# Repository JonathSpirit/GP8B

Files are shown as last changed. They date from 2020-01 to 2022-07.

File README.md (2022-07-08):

# GP8B - GProcessor8Bits

Copyright (C) 2022 Guillaume Guillet\
Licensed under CERN-OHL-W v2 or later

<table border="0px">
<tr>
<td>
This source describes Open Hardware and is licensed under the CERN-OHL-W v2 or later.
</td>
</tr>
<tr>
<td>
You may redistribute and modify this documentation and make products
using it under the terms of the CERN-OHL-W v2 (https:/cern.ch/cern-ohl).
This documentation is distributed WITHOUT ANY EXPRESS OR IMPLIED
WARRANTY, INCLUDING OF MERCHANTABILITY, SATISFACTORY QUALITY
AND FITNESS FOR A PARTICULAR PURPOSE. Please see the CERN-OHL-W v2
for applicable conditions.
</td>
</tr>
</table>

Made with [Kicad](https://kicad.org/)

## Description
G_Processor8Bits is a homemade, without any microcontroller, 8bits processor.

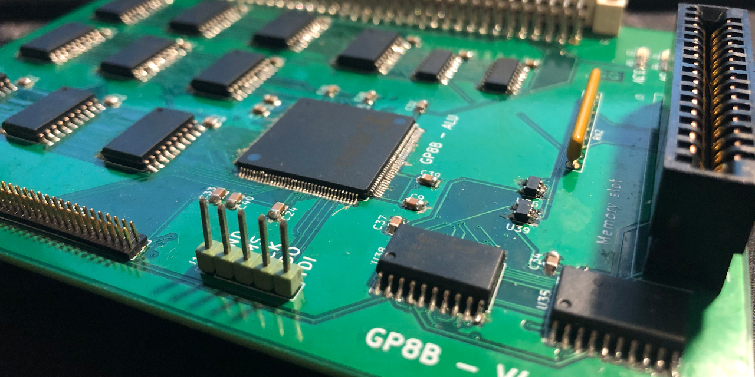
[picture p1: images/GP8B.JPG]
GP8B_image
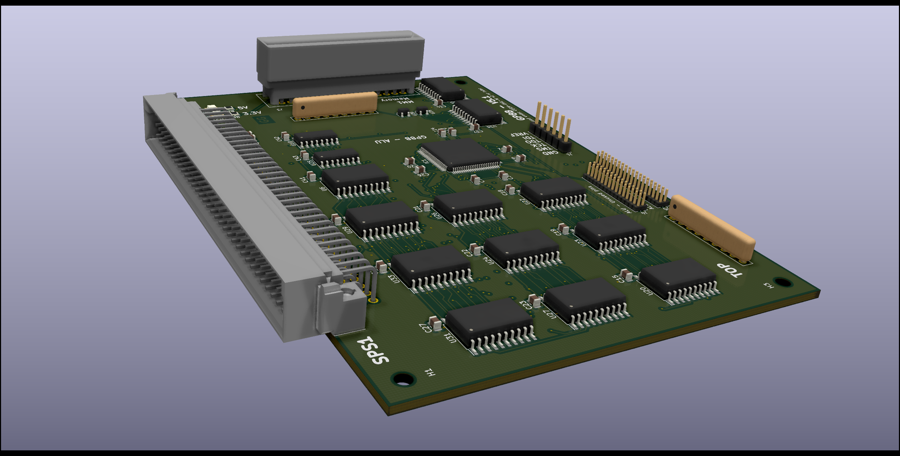
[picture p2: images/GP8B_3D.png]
GP8B_3D_image
 
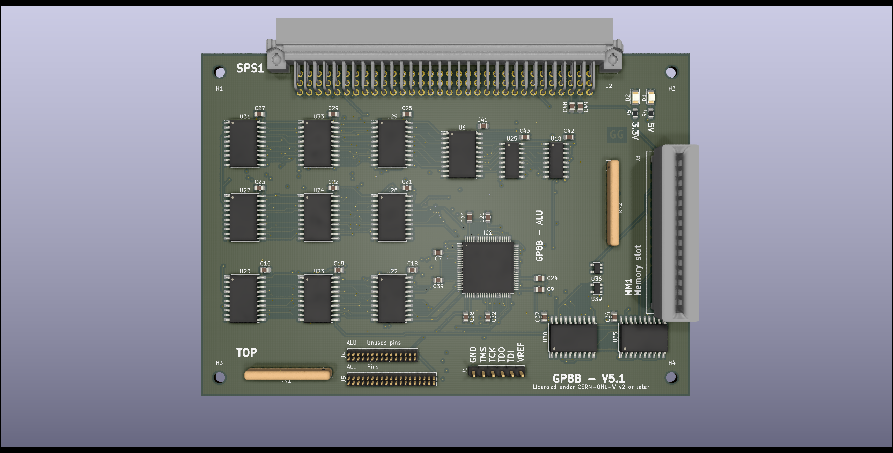
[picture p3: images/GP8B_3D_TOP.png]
GP8B_3D_TOP_image
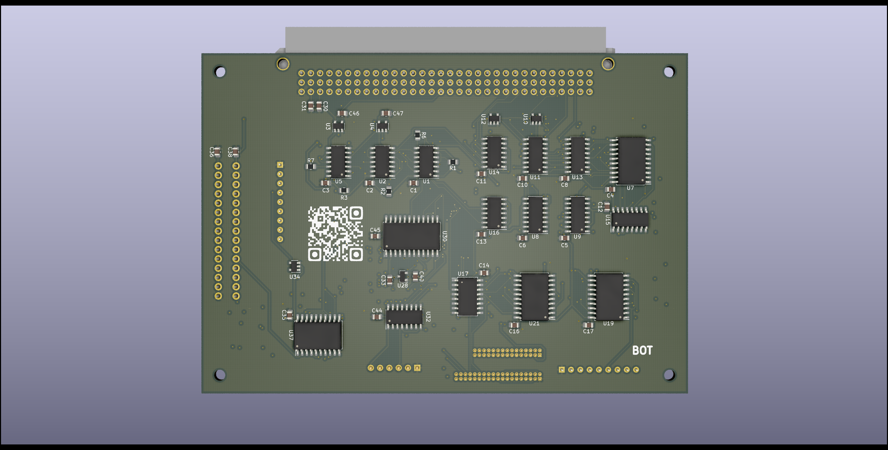
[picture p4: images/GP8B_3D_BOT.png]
GP8B_3D_BOT_image
 

## Stats





\
\
\


## Block diagram

[Block diagram (.pdf)](documents/blockDiagram/GP8B_blockDiagram.pdf)

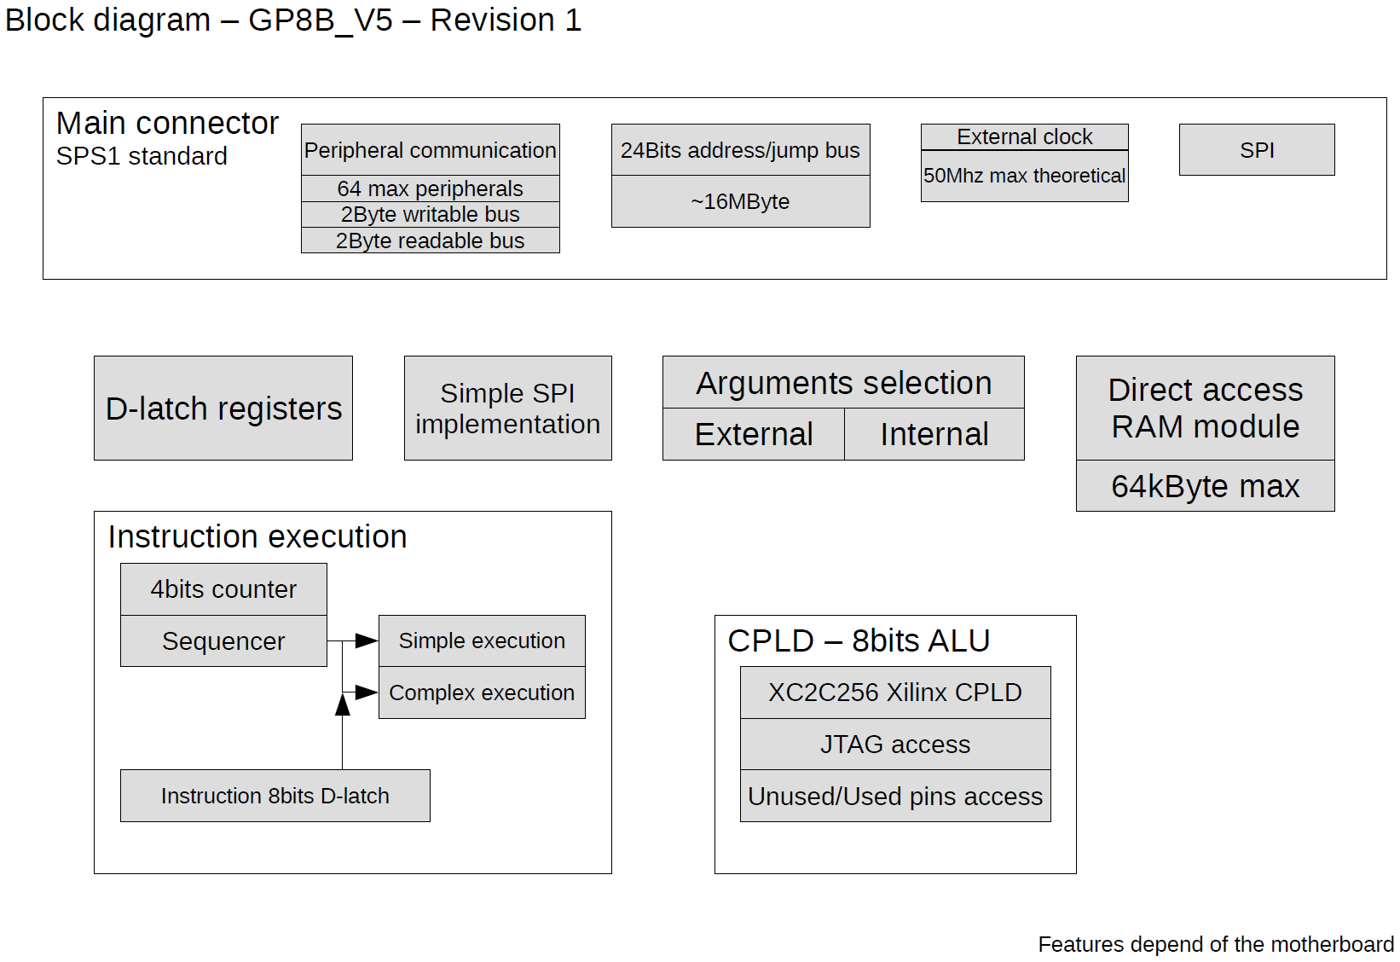
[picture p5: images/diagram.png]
Image of diagram


## Instruction sets
GP8B follow [CodeG_binary (revision 1)](https://github.com/JonathSpirit/GComputer_standard)

8bits instuction is separated in 2 category :
```
-------------- Argument selection
|||  
||| ---------- Opcode
||| |||||
000 00000
```
**5bits for opcode :**
```
OPCODE      HEX     NAME            DESCRIPTION
xxx0’0000   0x00    BWRITE1_CLK     Apply value to bus “write 1”.
xxx0’0001   0x01    BWRITE2_CLK     Apply value to bus “write 2”.
xxx0’0010   0x02    BPCS_CLK        Apply value to bus “peripheral CS”.
xxx0’0011   0x03    OPLEFT_CLK      Apply value to the left operation.
xxx0’0100   0x04    OPRIGHT_CLK     Apply value to the right operation.
xxx0’0101   0x05    OPCHOOSE_CLK    Apply value for choosing the operation.
xxx0’0110   0x06    PERIPHERAL_CLK  Send a clock pulse to the peripheral.
xxx0’0111   0x07    BJMPSRC1_CLK    Apply value to bus “jump source 1”.
xxx0’1000   0x08    BJMPSRC2_CLK    Apply value to bus “jump source 2”.
xxx0’1001   0x09    BJMPSRC3_CLK    Apply value to bus “jump source 3”.
xxx0’1010   0x0A    JMPSRC_CLK      Jump to the address of “jump source”.
xxx0’1011   0x0B    BRAMADD1_CLK    Apply value to bus “RAM address 1”.
xxx0’1100   0x0C    BRAMADD2_CLK    Apply value to bus “RAM address 2”.
xxx0’1101   0x0D    SPI_CLK         Send a clock pulse for the SPI.
xxx0’1110   0x0E    BCFG_SPI_CLK    Apply value to the config bus SPI.
xxx0’1111   0x0F    STICK           Simple tick, do nothing (delay).
xxx1’0000   0x10    IF              Conditional instruction.
xxx1’0001   0x11    IFNOT           Conditional instruction inverted.
xxx1’0010   0x12    RAMW            Write value to the actual address of the memory.
xxx1’0011   0x13    UOP             Undefined operation.
xxx1’0100   0x14    UOP             Undefined operation.
xxx1’0101   0x15    UOP             Undefined operation.
xxx1’0110   0x16    UOP             Undefined operation.
xxx1’0111   0x17    LTICK           Long tick, do nothing (delay).
```
**3bits for argument selection :**
```
OPCODE      HEX     NAME            DESCRIPTION
000x’xxxx   0x00    SRCVALUE        The value stored to the source.
001x’xxxx   0x20    BREAD1          The value of the read bus 1.
010x’xxxx   0x40    BREAD2          The value of the read bus 2.
011x’xxxx   0x60    OPRESULT        The value of the operation result (ALU).
100x’xxxx   0x80    RAMVALUE        The value of the processor memory.
101x’xxxx   0xA0    SPI             The value of the SPI.
110x’xxxx   0xC0    EXT_1           External value 1.
111x’xxxx   0xE0    EXT_2           External value 2.
```

## Processor standard
This processor, follow the [SPS1](https://github.com/JonathSpirit/GComputer_standard) standard

## Compatibility
Compatible with all motherboard following the [MOM1_SPS1](https://github.com/JonathSpirit/GComputer_standard) standard

## Documents
[Block diagram (.pdf)](documents/blockDiagram/GP8B_blockDiagram.pdf)

[Schematics (.pdf)](documents/GP8B_schematics.pdf)

[Materials (.pdf)](documents/GP8B_materials.pdf)

[Datasheet (.pdf)](documents/GP8B_datasheet.pdf)

## Contributing / Questions
Please see [Contributing file](CONTRIBUTING.md)

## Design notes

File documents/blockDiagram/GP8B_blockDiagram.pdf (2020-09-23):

## Main connector

SPS1 standard

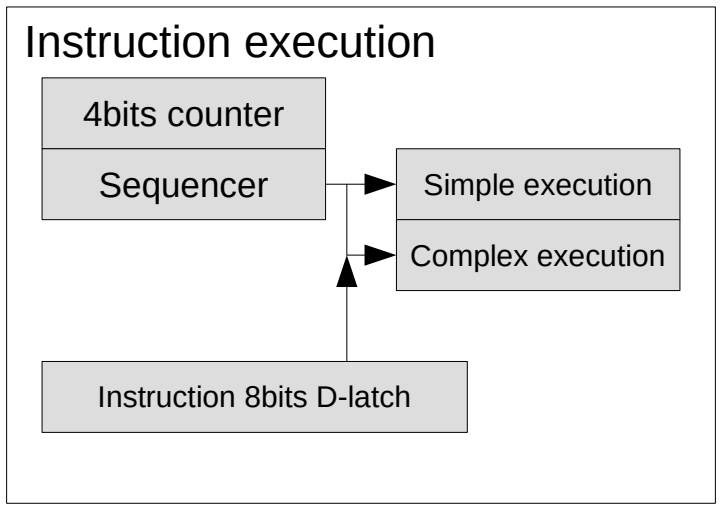
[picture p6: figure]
Instruction execution; 4bits counter; Sequencer; Instruction 8bits D-latch; Simple execution; Complex execution

## CPLD – 8bits ALU

## D-latch registers

Arguments selection | Direct access RAM module

### Simple SPI implementation

## External Internal 64kByte max

External clock

50Mhz max theoretical

Peripheral communication 24Bits address/jump bus 64 max peripherals

XC2C256 Xilinx CPLD

JTAG access

Unused/Used pins access

## Block diagram – GP8B_V5 – Revision 1

2Byte readable bus

2Byte writable bus

SPI

~16MByte

Features depend of the motherboard

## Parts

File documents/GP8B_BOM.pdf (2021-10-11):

1

GP8B_materials.fods

| GP8B | V5.1
Author : Guillaume Guillet | Revision 1 | Licensed under CERN-OHL-W v2 or later
Type | Value | Q | References | Package | Manufacturer | Store | Store ID | Unit price* | Price
C | 10nF | 33 | C1 to C6, C8, C10 to C19, C21 to C23, C25, C27, C29, C34, C35, C37, C41 to C47 | C_0805_2012Metric | Wurth Elektronik | Mouser | 710-885012207066 | 0.033 | 1.089
| 100nF | 12 | C7, C9, C20, C24, C26, C28, C30 to C32, C36, C38, C39 | C_0805_2012Metric | Wurth Elektronik | Mouser | 710-885012207072 | 0.072 | 0.864
| 1uF | 4 | C33, C40, C48, C49 | C_0805_2012Metric | Wurth Elektronik | Mouser | 710-885012207078 | 0.094 | 0.376
U | 74AHC08 | 2 | U16,U14 | SOIC-14_3.9x8.7mm_P1.27mm | Texas Instruments | Mouser | 595-SN74AHC08QDRQ1 | 0.459 | 0.918
| 74AHC273 | 9 | U6, U24, U26, U27, U29, U31, U33, U35, U37 | SOIC-20W_7.5x12.8mm_Pitch1.27mm | Texas Instruments | Mouser | 595-SN74AHC273DWR | 0.431 | 3.879
| 74AHCT273 | 1 | U7 | SOIC-20W_7.5x12.8mm_Pitch1.27mm | Texas Instruments | Mouser | 595-SN74AHCT273DWR | 0.524 | 0.524
| 74HC163 | 1 | U8 | SOIC-16_3.9x9.9mm_P1.27mm | Texas Instruments | Mouser | 595-SN74HC163D | 0.421 | 0.421
| CD74AC238 | 4 | U9, U11, U13, U15 | SOIC-16_3.9x9.9mm_P1.27mm | Texas Instruments | Mouser | 595-CD74AC238M96 | 0.591 | 2.364
| 74AHCT244 | 5 | U19 à U23 | SOIC-20W_7.5x12.8mm_Pitch1.27mm | Texas Instruments | Mouser | 595-SN74AHCT244DWR | 0.478 | 2.39
| 74AHC138 | 1 | U17 | SOIC-16W_5.3x10.2mm_P1.27mm | Texas Instruments | Mouser | 595-SN74AHC138NSR | 0.394 | 0.394
| 74HC166 | 1 | U18 | SOIC-16_3.9x9.9mm_P1.27mm | Texas Instruments | Mouser | 595-SN74HC166DRE4 | 0.45 | 0.45
| 74LVC1G34 | 1 | U34 | SOT-23-5 | Texas Instruments | Mouser | 595-SN74LVC1G34DBVR | 0.3 | 0.3
| 74AHCT595 | 1 | U25 | SOIC-16_3.9x9.9mm_P1.27mm | Texas Instruments | Mouser | 595-SN74AHCT595DR | 0.431 | 0.431
| 74AHC05 | 3 | U1, U2, U5 | SOIC-14_3.9x8.7mm_P1.27mm | Texas Instruments | Mouser | 595-SN74AHC05D | 0.431 | 1.293
| 74AHC374 | 1 | U38 | SOIC-20W_7.5x12.8mm_Pitch1.27mm | Texas Instruments | Mouser | 595-SN74AHC374DWR | 0.524 | 0.524
| 74AHC1G04 | 4 | U10, U12, U36, U39 | SOT-23-5 | Texas Instruments | Mouser | 595-SN74AHC1G04DBVR | 0.3 | 1.2
| 74AHC1G02 | 1 | U3 | SOT-23-5 | Texas Instruments | Mouser | 595-SN74AHC1G02DBE4 | 0.45 | 0.45
| 74AHC1G08 | 1 | U4 | SOT-23-5 | Texas Instruments | Mouser | 595-SN74AHC1G08DBV3 | 0.421 | 0.421
| TPS7A0518PDBZR | 1 | U28 | SOT-23-3 | Texas Instruments | Mouser | 595-TPS7A0518PDBZR | 0.591 | 0.591
| SN74LVC8T245DW | 1 | U30 | SOIC-24W_7.5x15.4mm_P1.27mm | Texas Instruments | Mouser | 595-SN74LVC8T245DWR | 1.01 | 1.01
| SN74LVC4T245D | 1 | U32 | SOIC-16_3.9x9.9mm_P1.27mm | Texas Instruments | Mouser | 595-SN74AVC4T245D | 1.04 | 1.04
| XC2C256-VQ100 | 1 | IC1 | VQFP-100_14x14mm_P0.5mm | Xilinx Inc, | Mouser | 217-XC2C256-7VQG100C | 18.08 | 18.08
R | 470E | 1 | R5 | R_0805_2012Metric | Bourns | Mouser | 652-CR0805FX-4700ELF | 0.094 | 0.094

# Project :

2

GP8B_materials.fods

| 1k5 | 1 | R4 | R_0805_2012Metric | Bourns | Mouser | 652-CR0805FX-1501ELF | 0.094 | 0.094
| 10k | 5 | R1, R2, R3, R6, R7 | R_0805_2012Metric | Bourns | Mouser | 652-CR0805-JW-103ELF | 0.094 | 0.47
RN | 8x10k | 2 | RN1, RN2 | R_Array_SIP9 | Bourns | Mouser | 652-4609H-1LF-10K | 0.562 | 1.124
D | GREEN_2.65V_2mA | 2 | D1, D2 | LED_1206_3216Metric | Kingbright | Mouser | 604-APT3216LZGCK | 0.414 | 0.828
J | TE_Eurocard_96pole | 1 | J2 | Eurocard_5650473-5 | TE connectivity | Mouser | 571-5650473-5 | 4.83 | 4.83
| 5530843-2 | 1 | J3 | TE_5530843-2 | TE connectivity | Mouser | 571-5530843-2 | 2.44 | 2.44
| Conn_01x06_Male | 1 | J1 | PinHeader_1x06_P2.54mm_Vertical | TE connectivity | Mouser | 571-826936-6 | 0.487 | 0.487
| Conn_02x15_Male | 1 | J4 | PinHeader_2x15_P1.27mm_Vertical | Samtec | Mouser | 200-TMS11501GD | 5.01 | 5.01
| Conn_02x19_Male | 1 | J5 | PinHeader_2x19_P1.27mm_Vertical | Samtec | Mouser | 200-TMS12001GD | 6.43 | 6.43
- | PCB_GP8B_V5.1 | 1 | - | - | G.Guillet | - | | | 0
Total price : | 60.816
*Depend of the quantity | Price is in CHF

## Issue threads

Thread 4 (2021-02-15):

Fix the SPI 4bits only issue

JonathSpirit, 2021-02-15:
by putting 74HC166 instead of 74HC165, it is possible to load directly 8bits into the serial shifter and do a much better SPI implementation

JonathSpirit, 2021-03-04:
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

Closed 2021-10-11.

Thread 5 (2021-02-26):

Replace symbol for IC1

JonathSpirit, 2021-02-26:
There is a new symbol in kicad for the XC2C256

Closed 2021-10-11.

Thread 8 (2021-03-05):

Don't go to the next address if the argument isn't SRCVALUE

JonathSpirit, 2021-03-05:
Currently when you are selecting an argument like th operation result (OPRESULT), you have to provide an dummy argument after the instruction in the code :

0x60 (BWRITE1_CLK instruction with an OPRESULT argument)
0x00 (dummy value)
0x61 (BWRITE2_CLK instruction with an OPRESULT argument)
0x00 (dummy value)
0xB2 (RAMW instruction with an SPI argument)
0x00 (dummy value)

The goal is to remove this dummy value when the user select another argument that SRCVALUE.
It will significantly decrease code size.

It will become like this :

0x60 (BWRITE1_CLK instruction with an OPRESULT argument)
0x61 (BWRITE2_CLK instruction with an OPRESULT argument)
0xB2 (RAMW instruction with an SPI argument)

JonathSpirit, 2021-03-05:
fed9e0c65bced2c1cab43c469c3624e4797e8039

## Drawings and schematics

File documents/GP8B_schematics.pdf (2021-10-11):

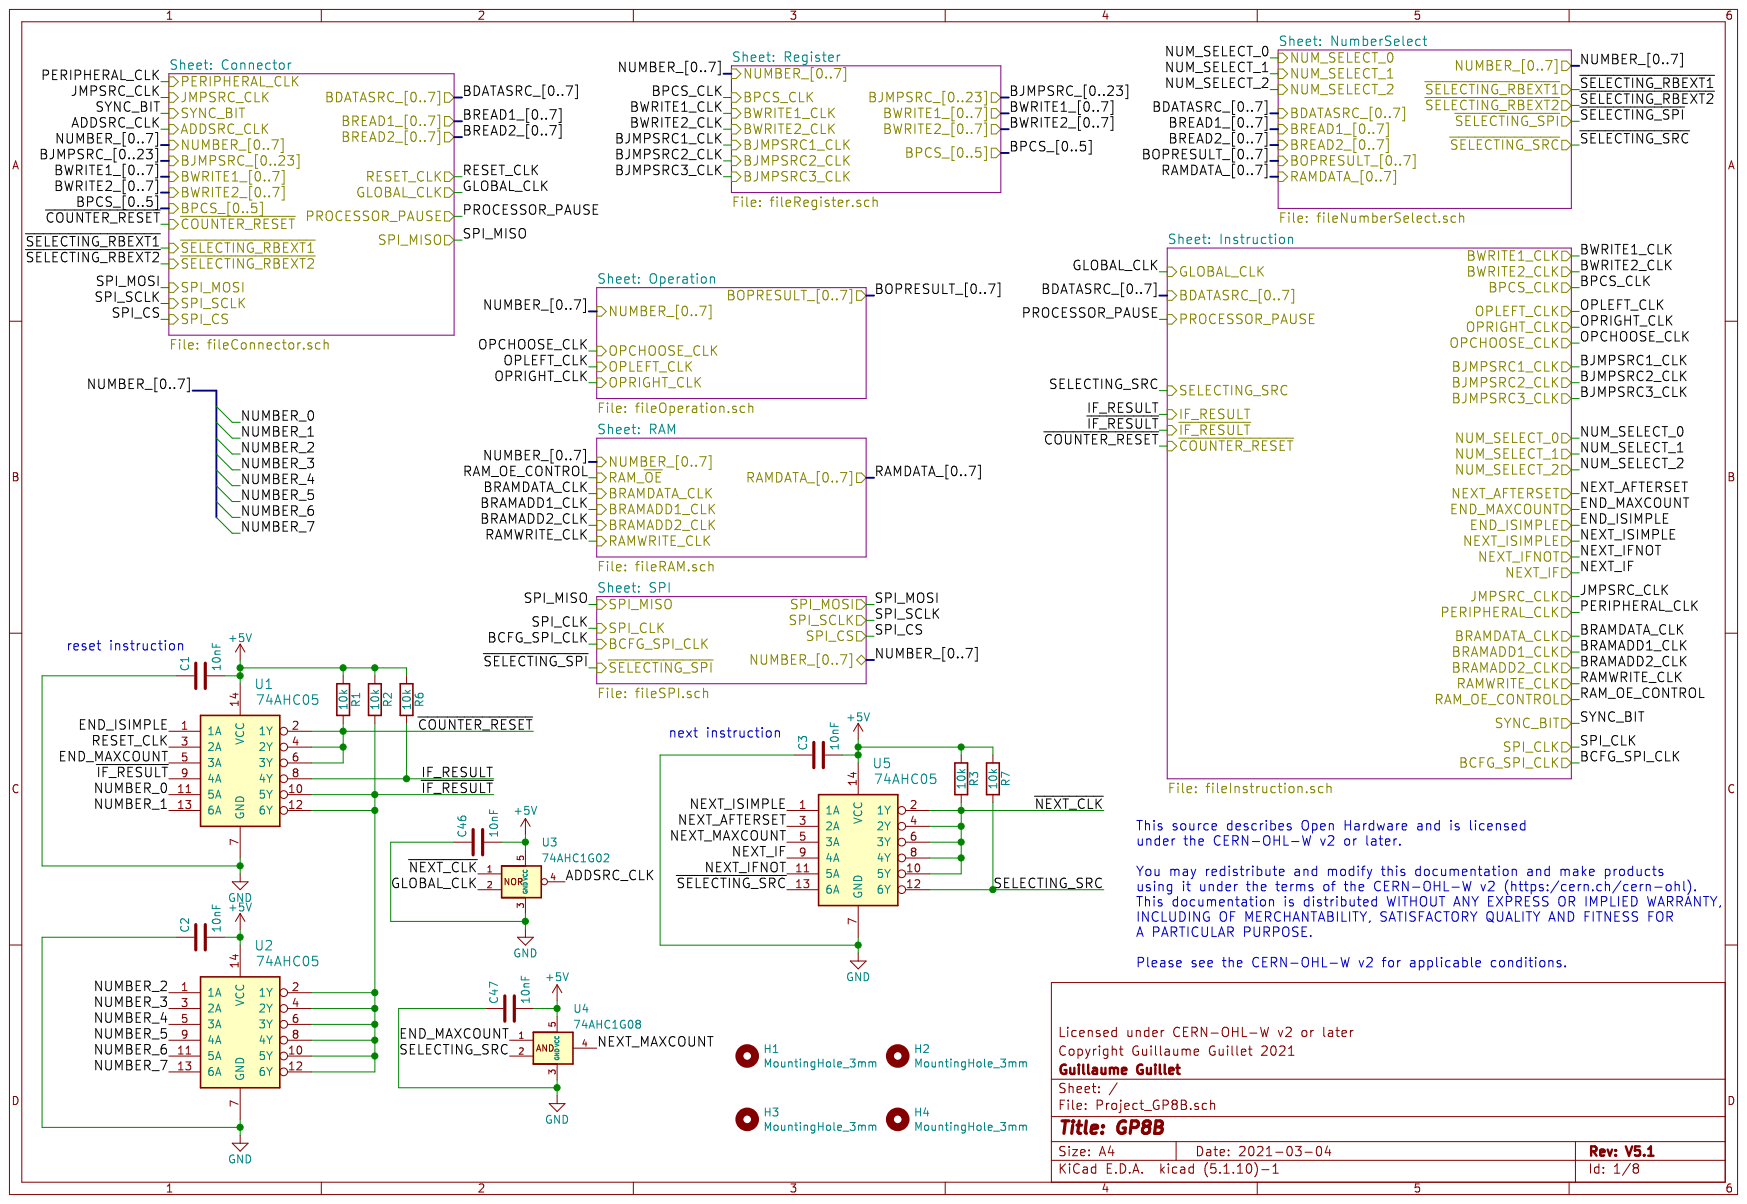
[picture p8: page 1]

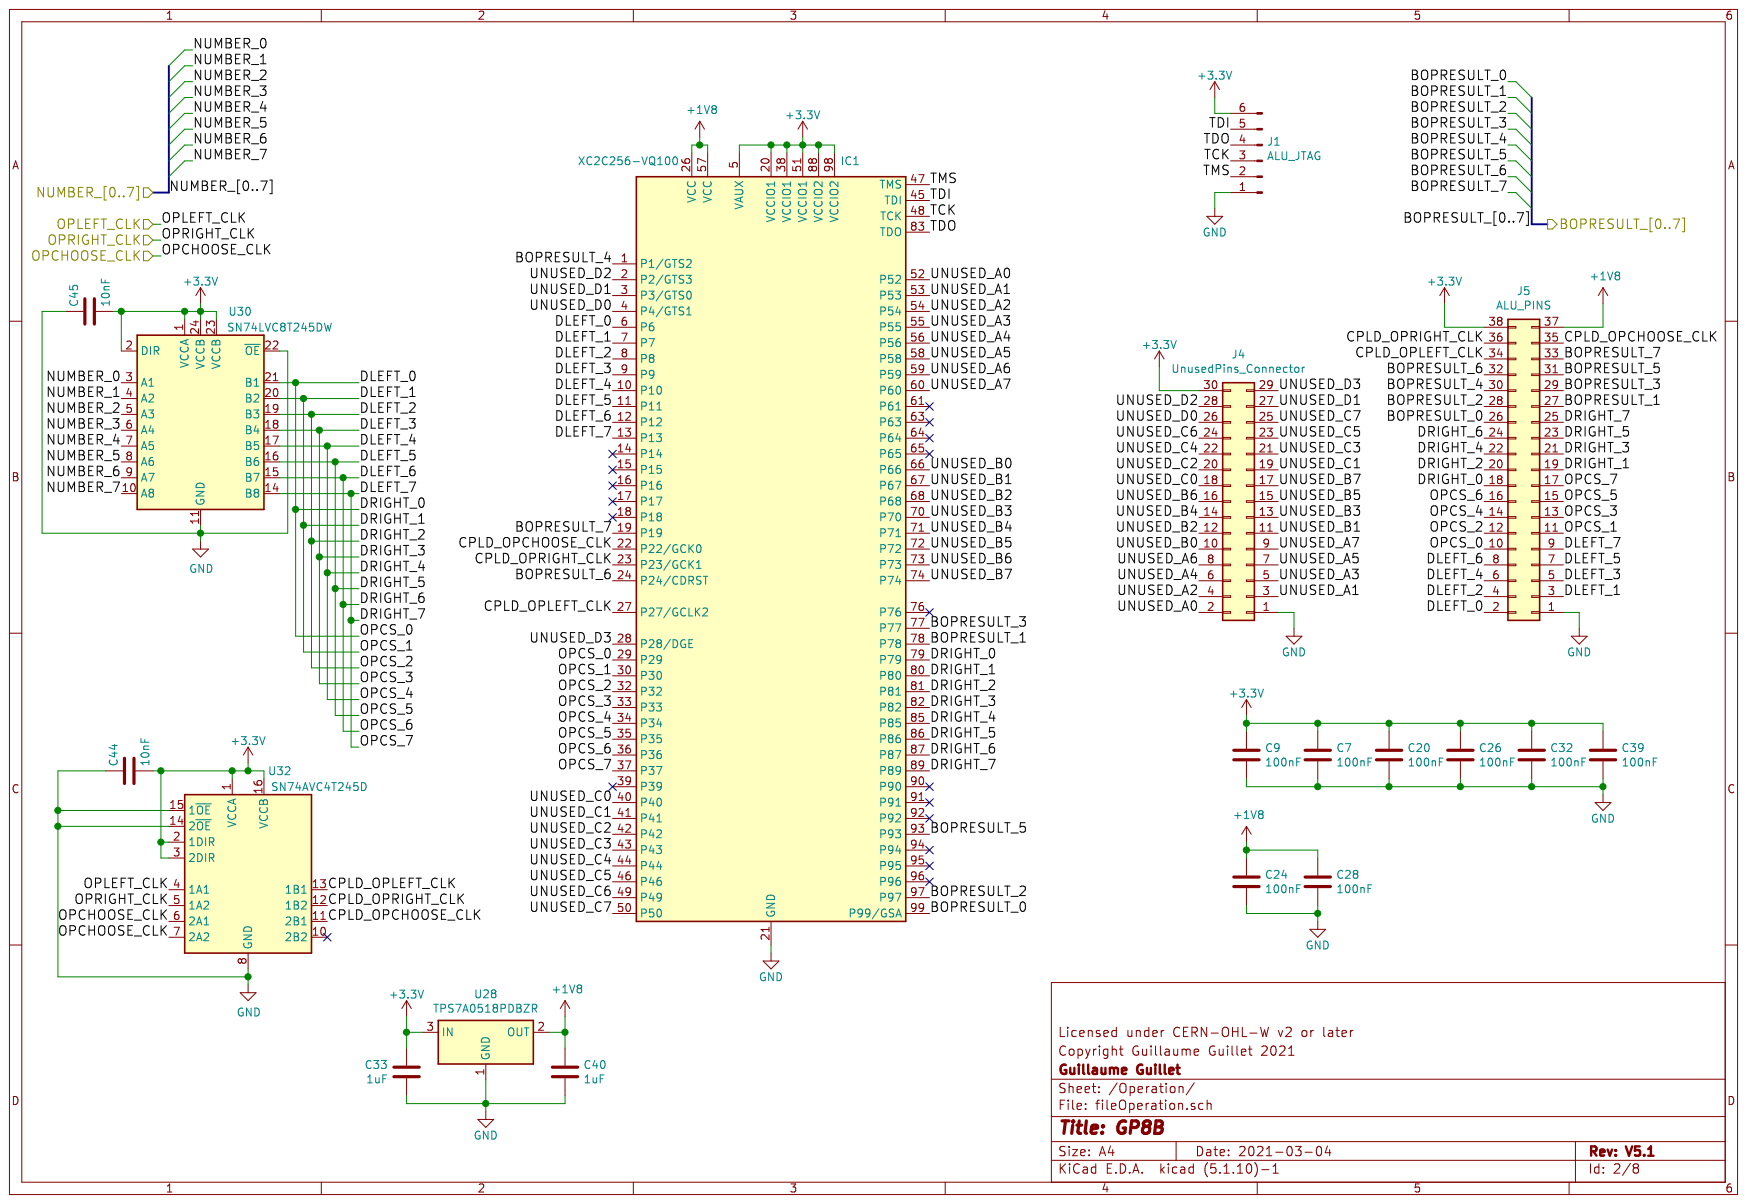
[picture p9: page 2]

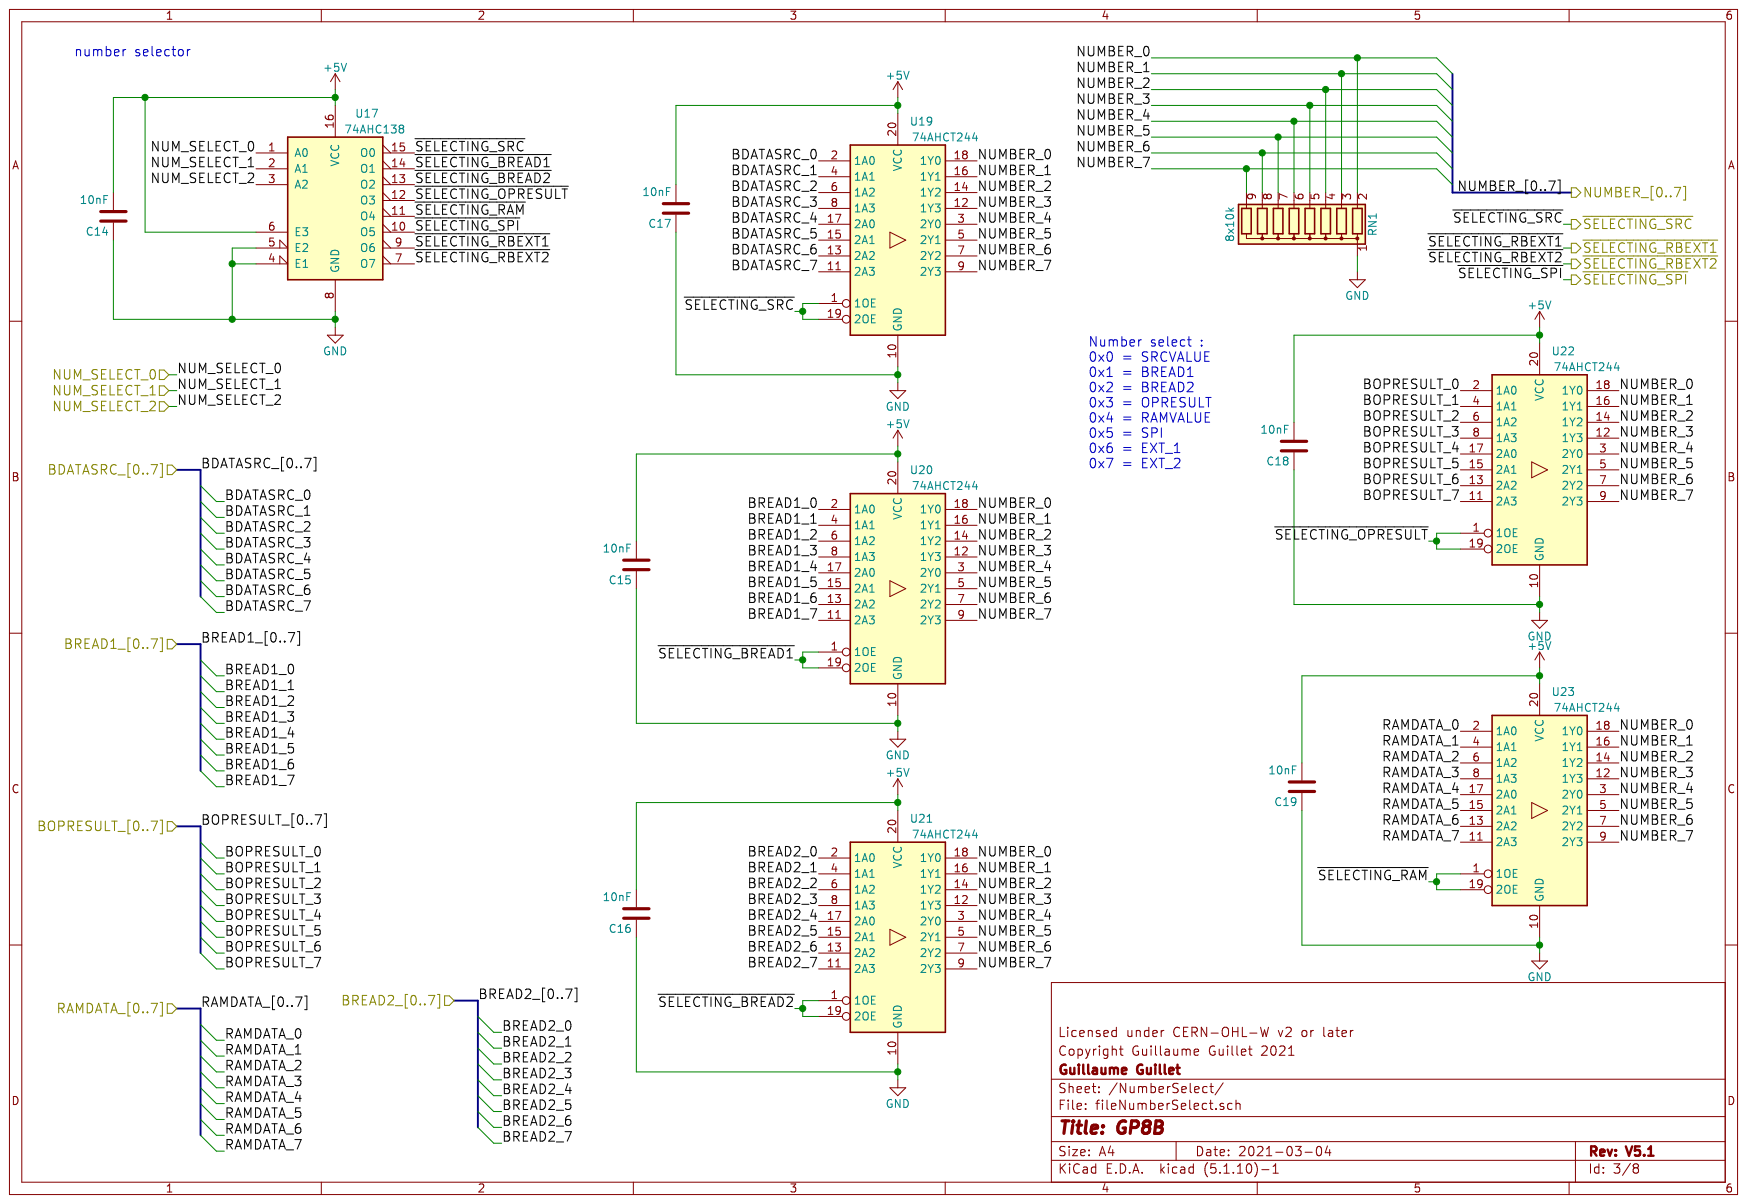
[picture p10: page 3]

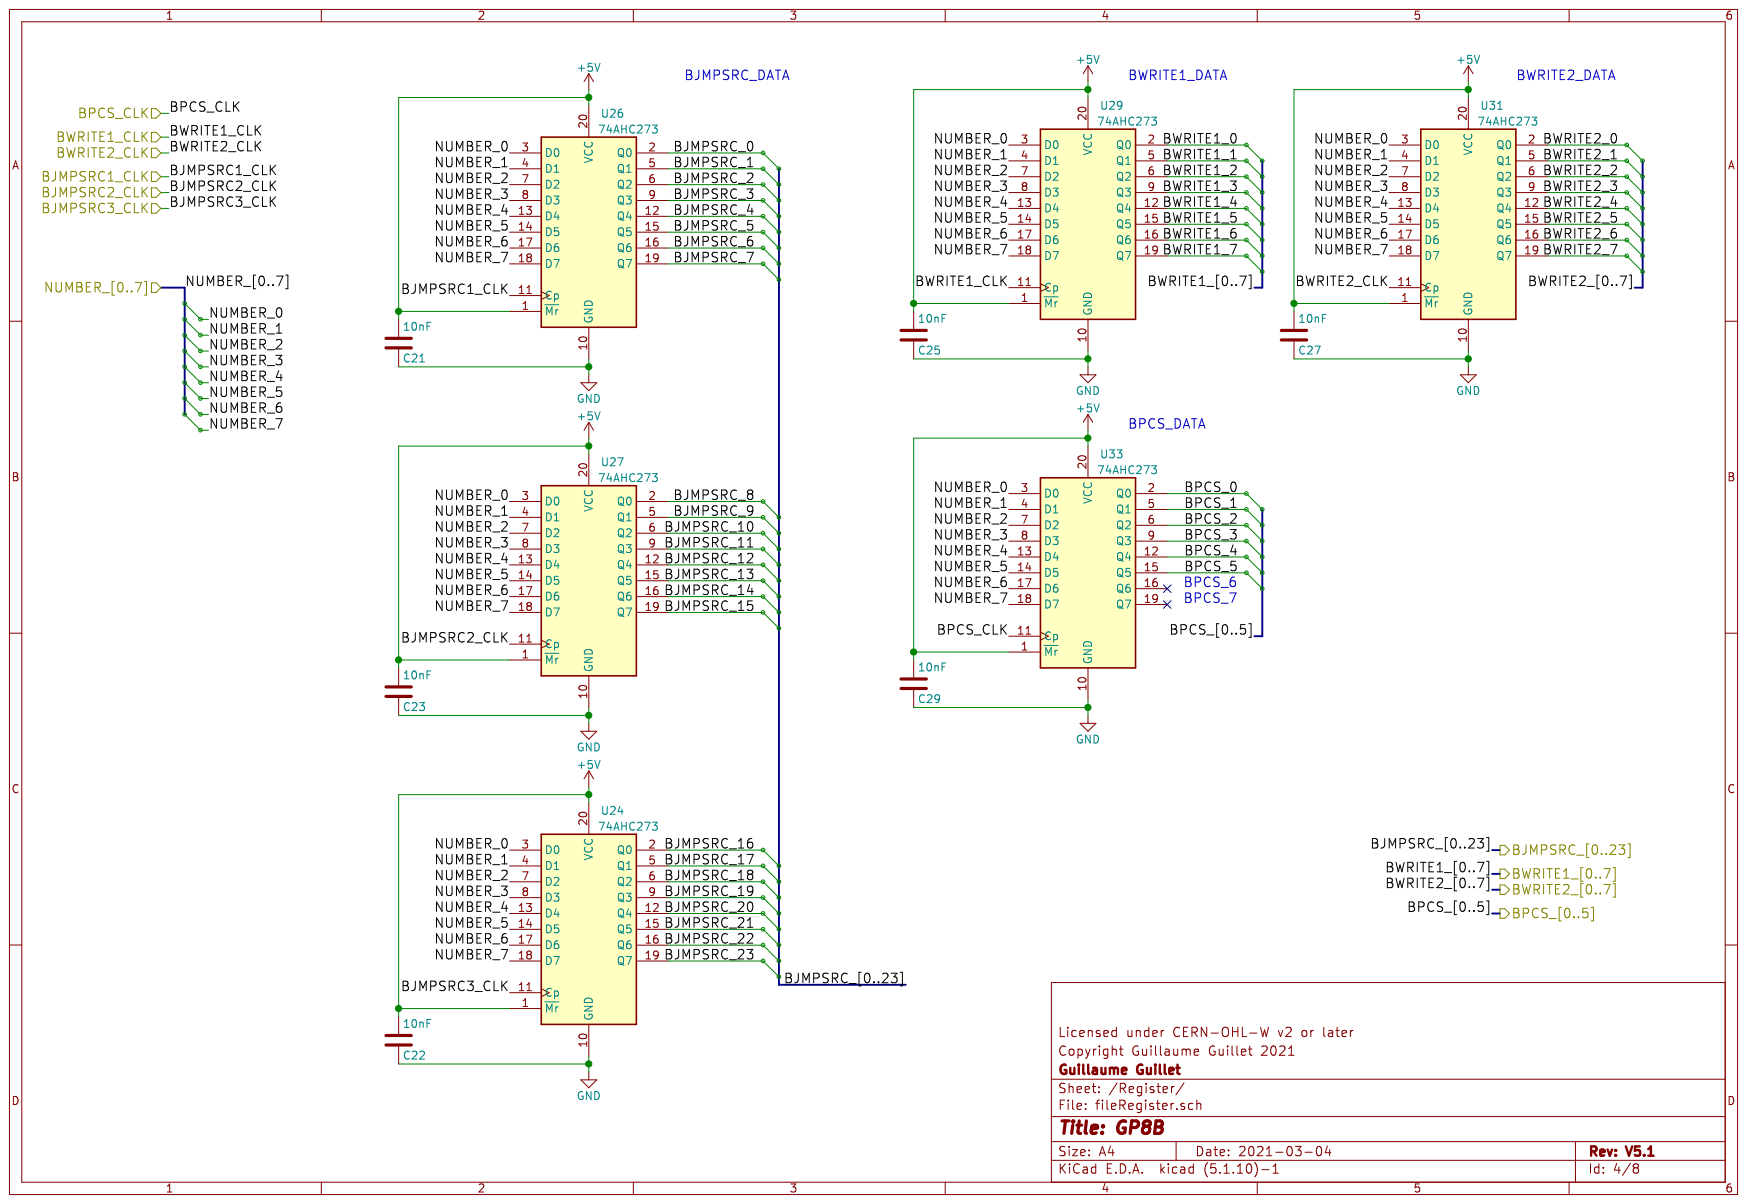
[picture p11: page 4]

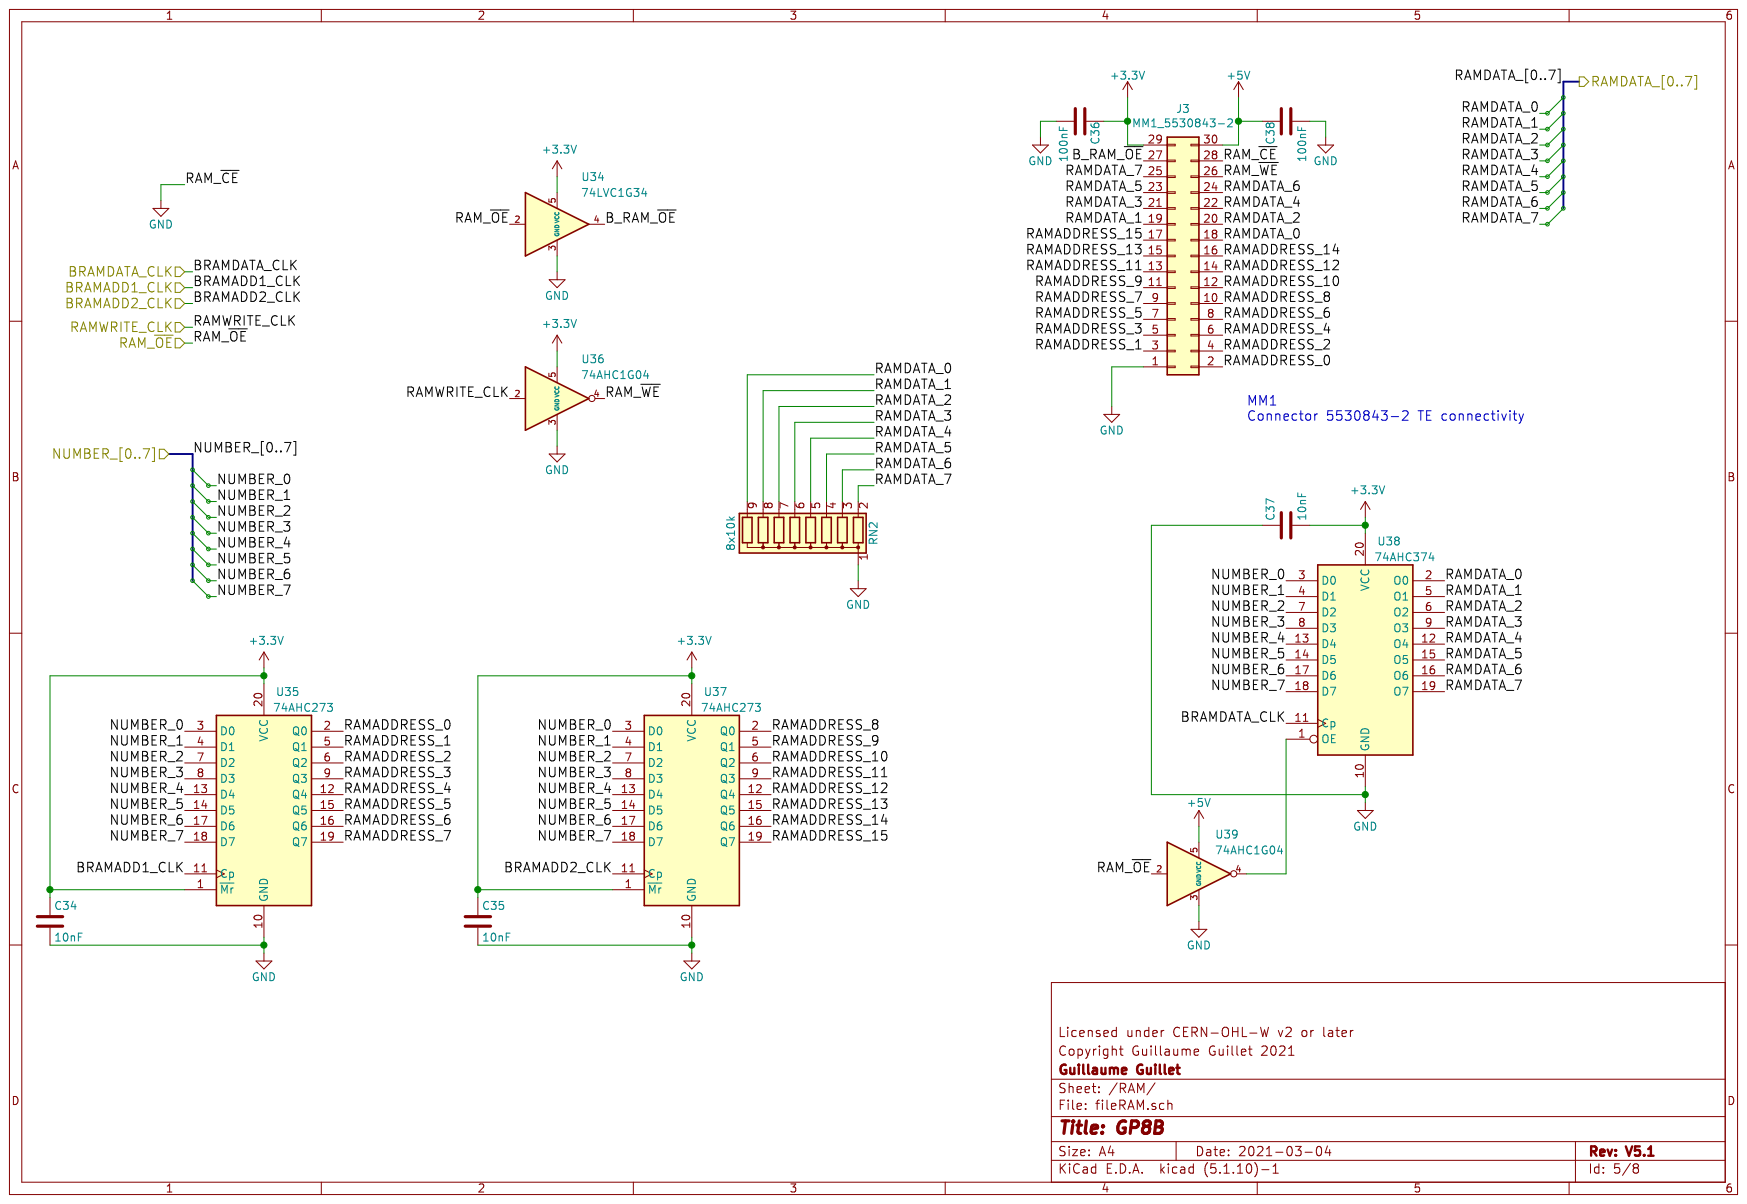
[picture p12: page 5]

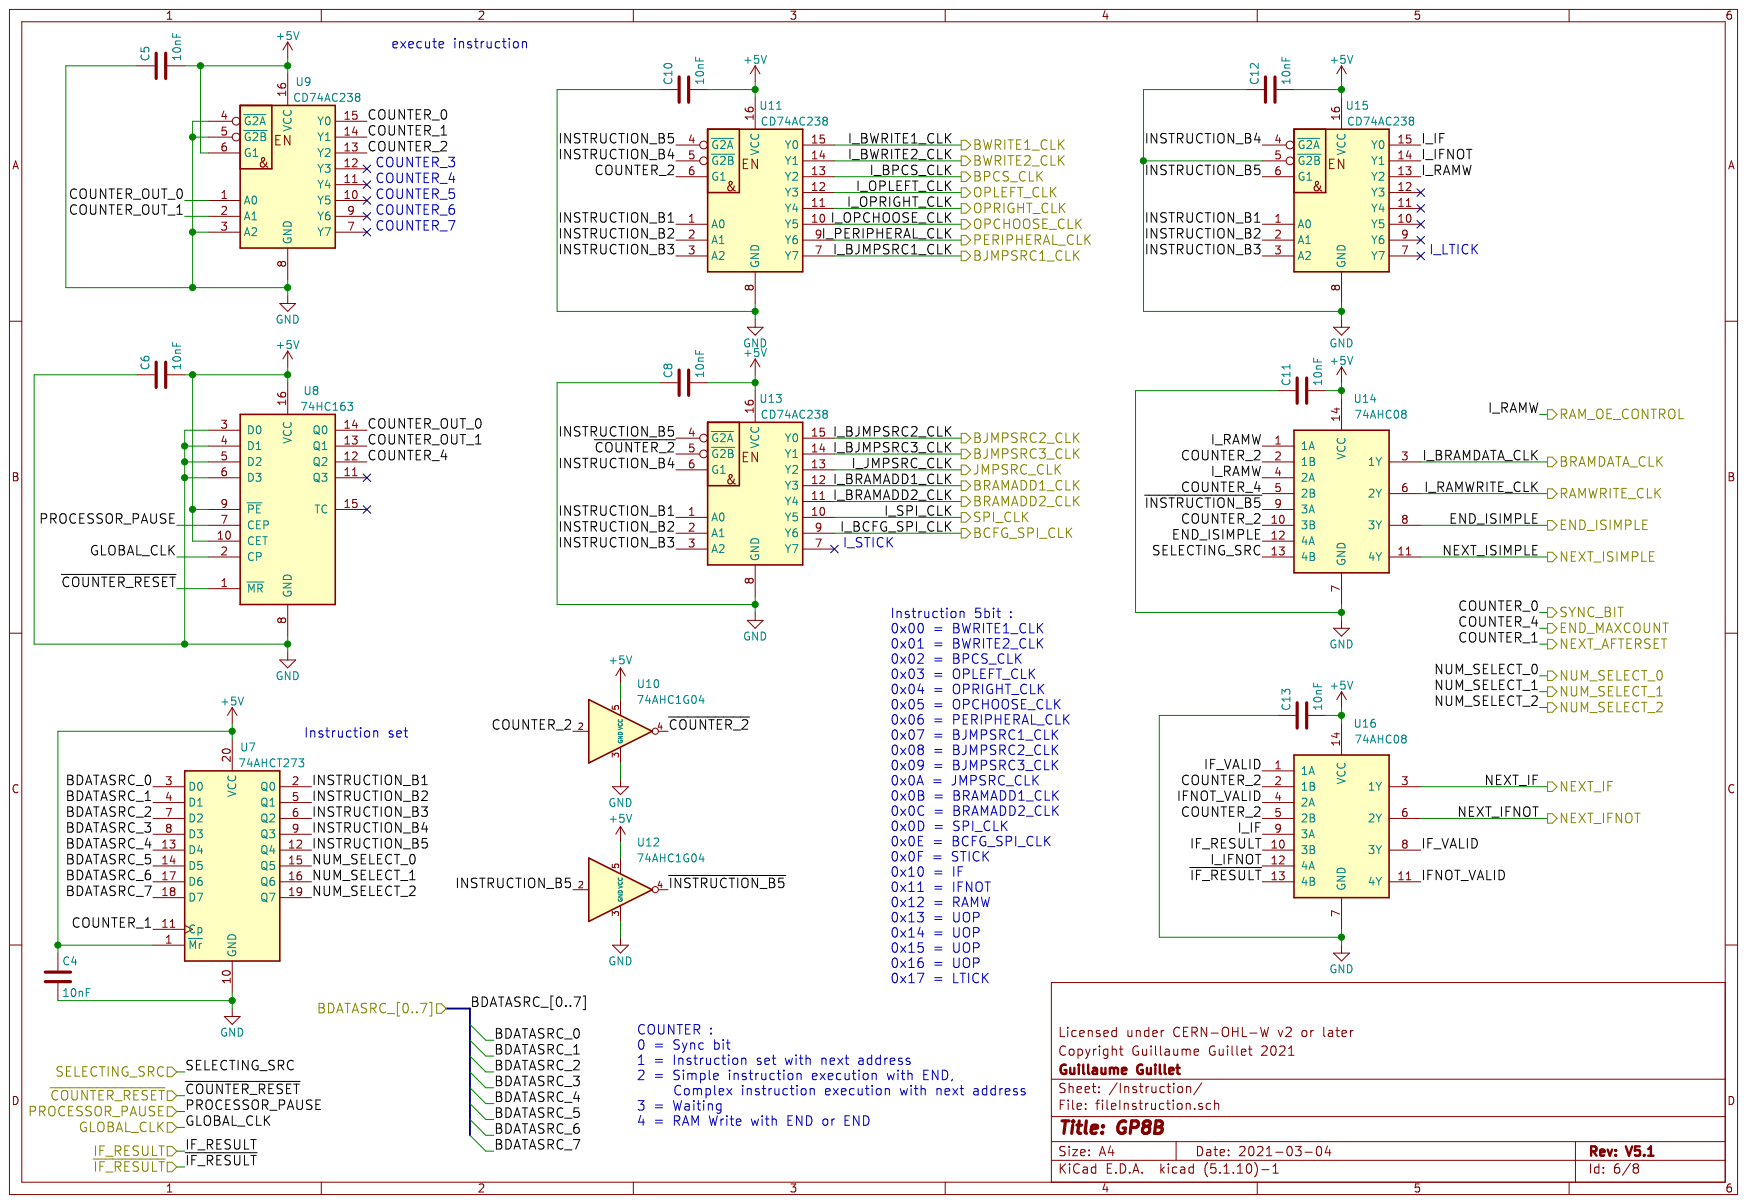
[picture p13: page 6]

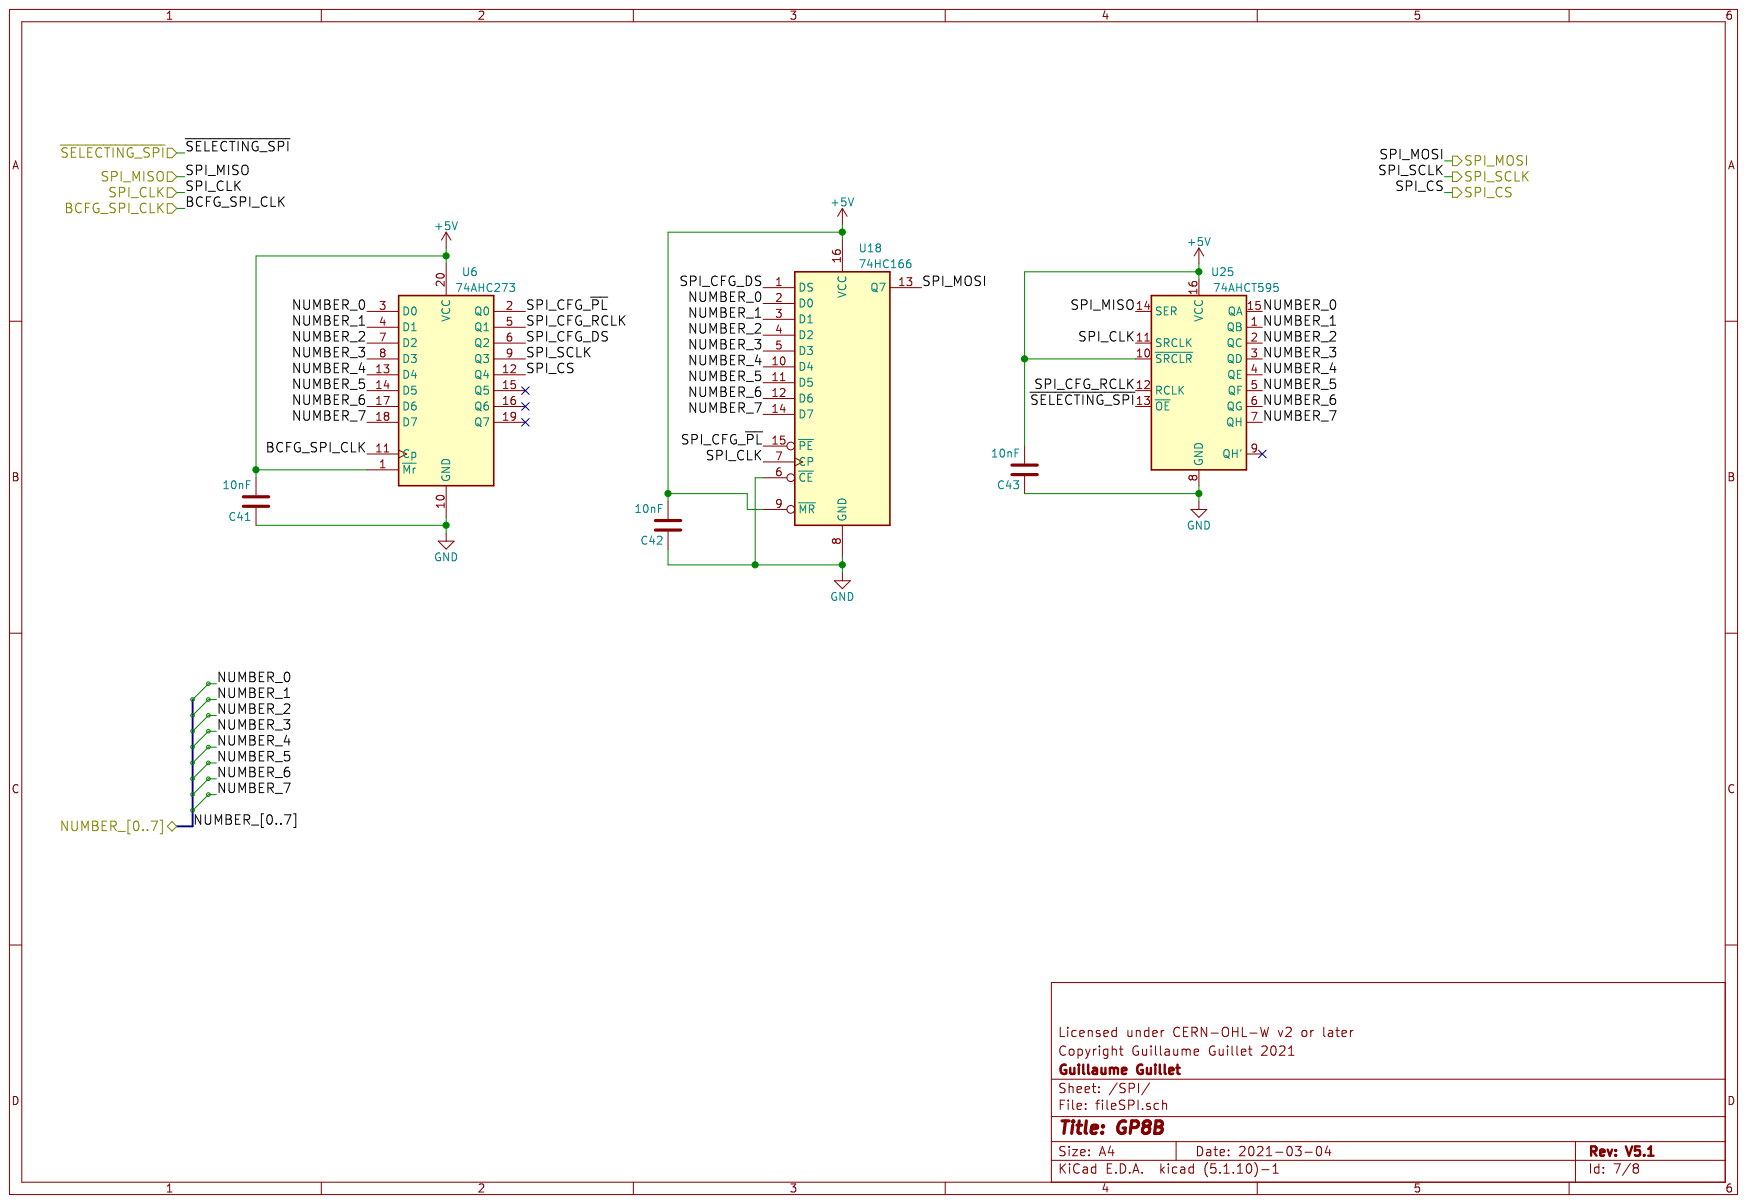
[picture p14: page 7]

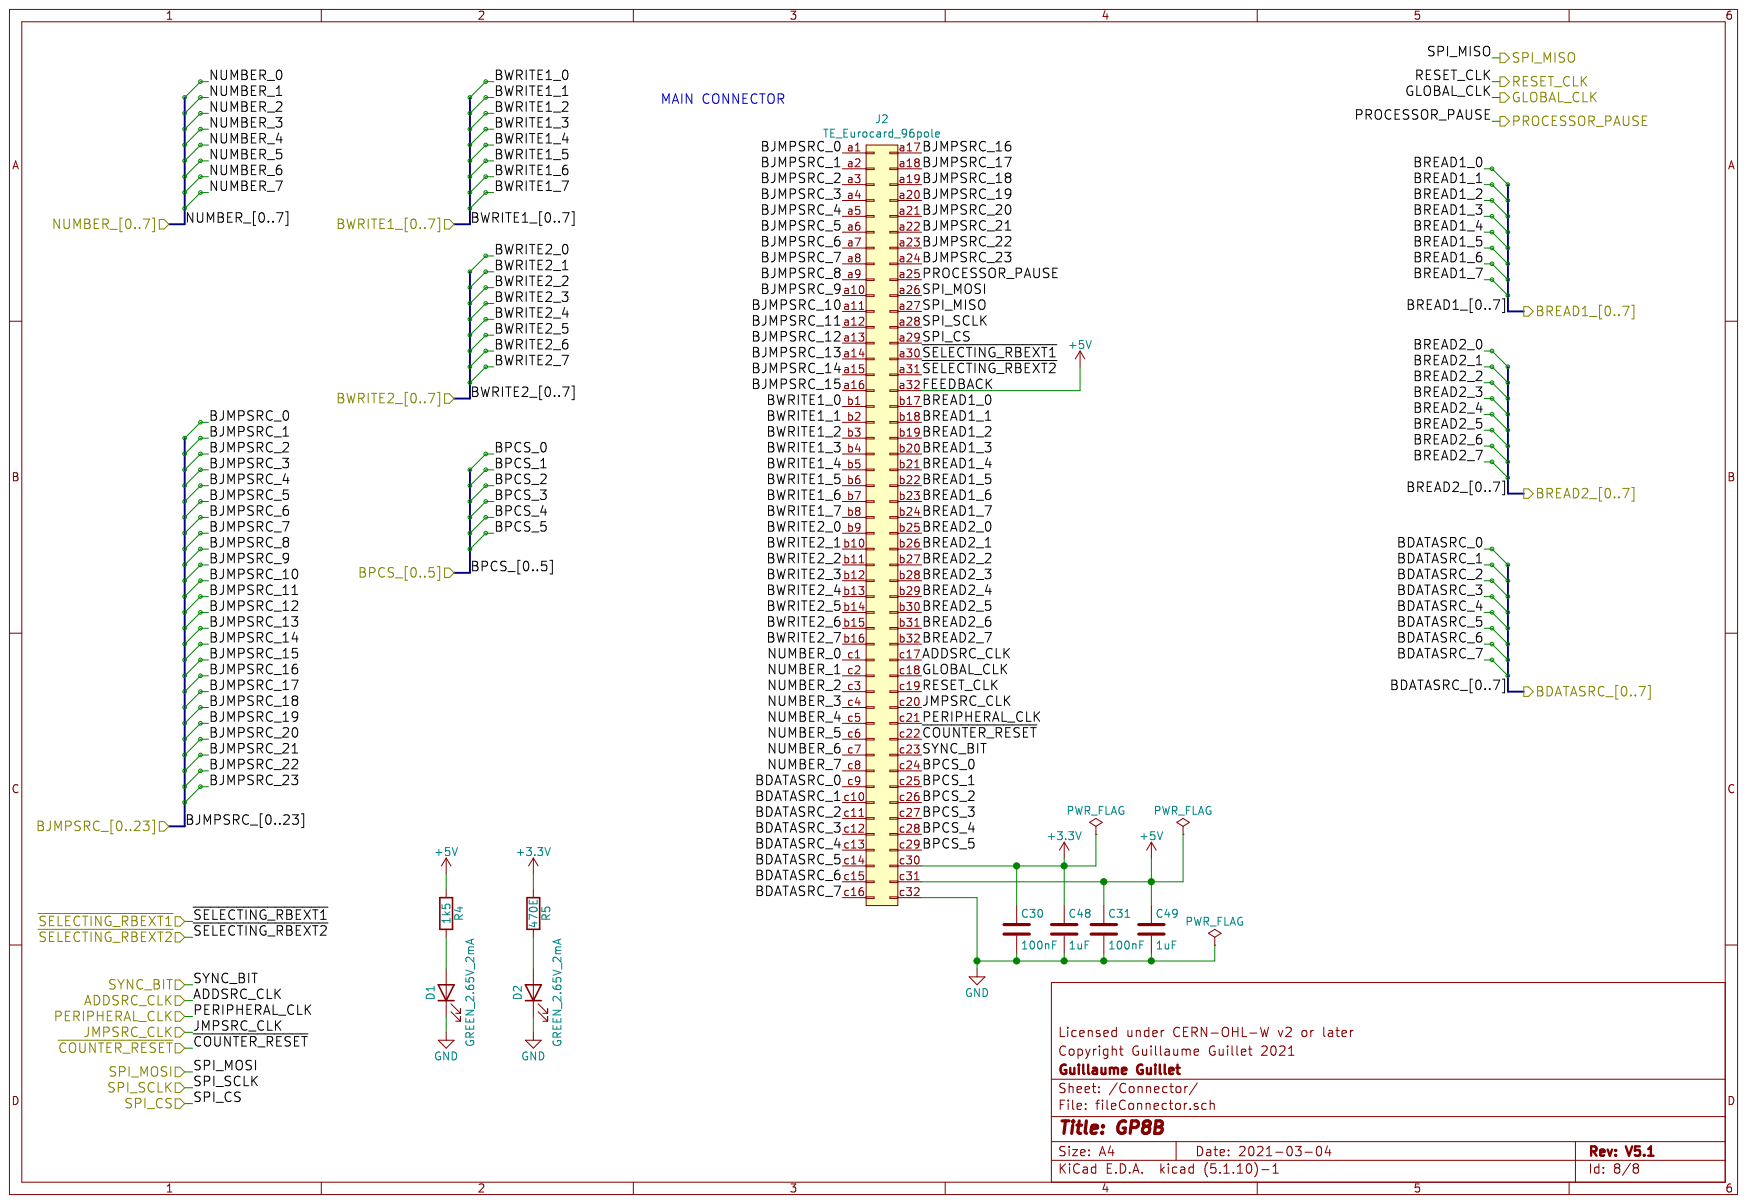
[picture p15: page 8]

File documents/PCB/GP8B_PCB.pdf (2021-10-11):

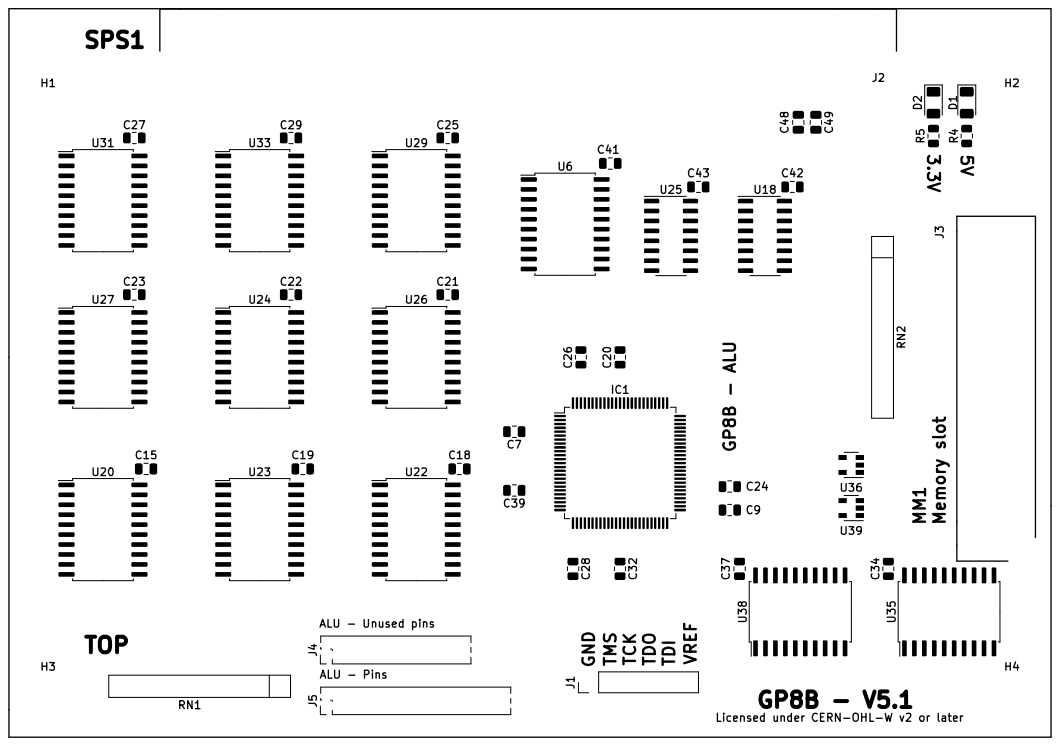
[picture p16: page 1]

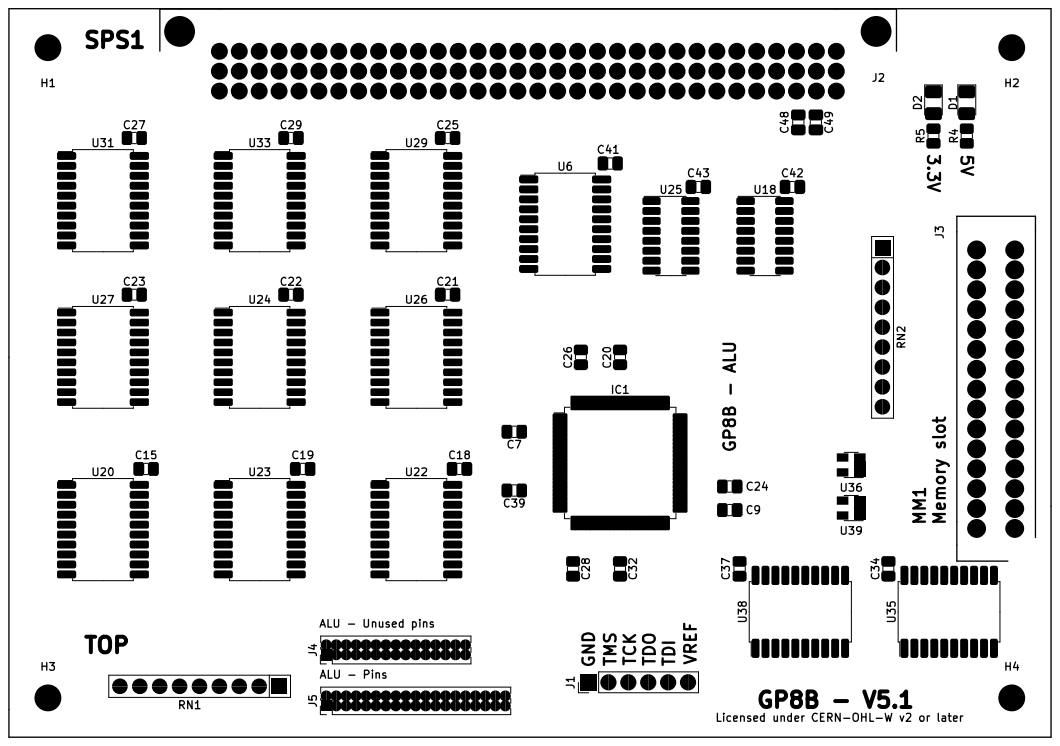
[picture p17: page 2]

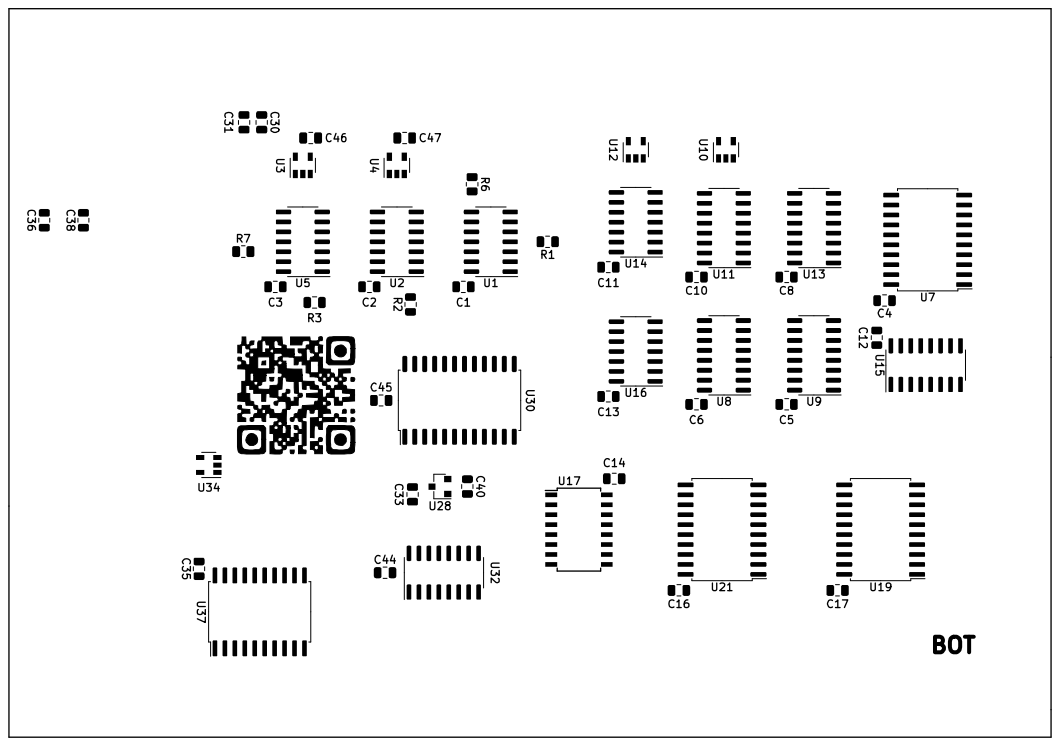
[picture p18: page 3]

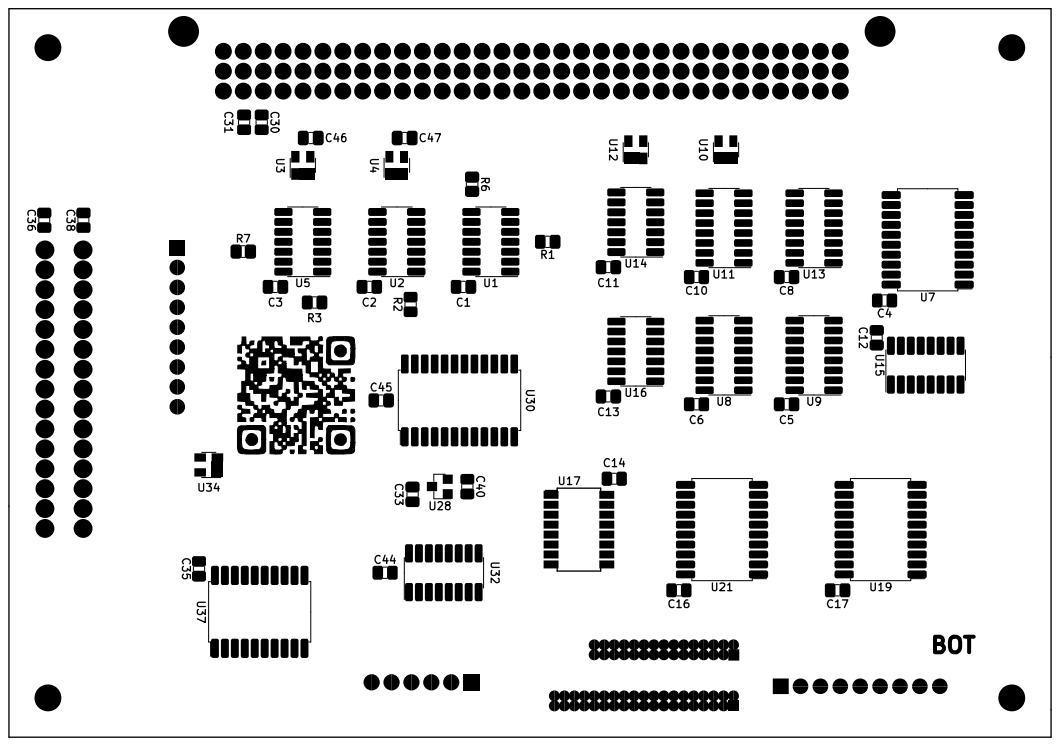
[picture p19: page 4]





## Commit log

2020-01-09 initial upload
    [5530843-2.stp, 5650473-5.stp, Connector.sch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]
2020-02-21 Adding license info on silks
    [Project_GP8B-B_Cu.gbr, Project_GP8B-B_Mask.gbr, Project_GP8B-B_SilkS.gbr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]
2020-03-09 Adding copyright and license notice
    [Connector.sch, Project_GP8B.kicad_pcb, Project_GP8B.sch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]
2020-04-11 Adding schematics in PDF
2020-04-11 Adding schematics (.pdf)
2020-05-18 Small documents cleaning
    [GP8BV4_material.ods]
2020-05-23 Small symbols changes, CHANGELOG, TPS7A0518PDBZR
    [Connector.sch, Project_GP8B.sch, Ram.sch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]
2020-05-23 Replacing CPLD, add 1.8V regulator, see CHANGELOG
    [fileOperation.sch]
2020-05-26 Switching license to "CERN-OHLw v2 or later"
    [Connector.sch, Project_GP8B.kicad_pcb, Project_GP8B.sch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]
2020-05-26 Adding SN74LVC8T245DW and SN74AVC4T245D
    [fileOperation.sch]
2020-06-02 Small fix/work-around for SPI
    [SPI.sch]
2020-06-02 Removing old symbols and unused footprints
2020-06-02 Small clean and mounting holes
    [Project_GP8B.sch]
2020-06-02 Renaming files, cleaning, CHANGELOG
    [Project_GP8B.sch, fileConnector.sch, fileInstruction.sch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]
2020-06-02 Removing duplication
    [fileRegistre.sch]
2020-06-09 Updating materials list
    [GP8BV4_material.ods, GP8B_materials.ods]
2020-06-09 Preparing footprint placement, removing old footprint
    [Project_GP8B.kicad_pcb]
2020-06-09 Exporting new schematics in PDF
2020-06-19 Footprints placement
    [Project_GP8B.kicad_pcb]
2020-06-30 Finishing material list
    [GP8B_materials.ods]
2020-07-01 Finishing the new PCB
    [Project_GP8B.kicad_pcb]
2020-07-01 Exporting new pcb to Gerbert,drl files
    [Project_GP8B-B_Cu.gbr, Project_GP8B-B_Mask.gbr, Project_GP8B-B_SilkS.gbr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]
2020-07-01 Exporting new PCB to pdf for fabrication
2020-07-01 Exporting material list to pdf
2020-08-11 .fods format for the materials
    [GP8B_materials.ods]
2020-08-14 Apply MM1 memory standard, and shared power pin symbol fix
    [Project_GP8B.kicad_pcb, Project_GP8B.sch, fileInstruction.sch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]
2020-08-14 Regenerate Gerbert files
    [Project_GP8B-B_Cu.gbr, Project_GP8B-B_Mask.gbr, Project_GP8B-B_SilkS.gbr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]
2020-08-18 Revert SPI 4bits problem work-around (finally this fixed nothing)
    [Project_GP8B.kicad_pcb, fileSPI.sch]
2020-08-18 Regenerating gerbert files
    [Project_GP8B-B_Cu.gbr, Project_GP8B-B_Mask.gbr, Project_GP8B-B_SilkS.gbr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]
2020-08-18 Update materials list
2020-08-18 Apply date (19.08.2020), QRcode fix
    [Project_GP8B.kicad_pcb, Project_GP8B.sch, fileConnector.sch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]
2020-08-18 Exporting schematics (.pdf)
2020-08-18 Exporting pcb placement (.pdf)
2020-09-23 Shifting J4 and J5 they were off the sheet.
    [fileOperation.sch]
2021-10-11 V5.1 (#9)
    * Apply new symbol for XC2C256-VQ100 #5
    * Set new date and 5.1
    * Replacing 74HC165 with 74HC166, and add SPI_CFG_DS #4
    * Replace some gates with a 74AHC1G02 to fix the pulse problem #3
    * Go next only if SRCVALUE, (simple instruction)
    * Remove weird ghost bus in register
    * Small cleaning in fileRegister
    * Go next only if SRCVALUE, (complex instruction) #8
    adding 74AHC1G08
    * Better decoupling #6
    * Component association (#7)
    * netlist
    * Updated BOM for V5.1
    * Routing, cleaning first pass
    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
    [Project_GP8B-B_Cu.gbr, Project_GP8B-B_Mask.gbr, Project_GP8B-B_SilkS.gbr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]
2021-11-08 Update README.md
    https://forum.kicad.info/t/warning-avoid-all-links-to-kicad-pcb-org-use-kicad-org/31521
2022-07-08 Transition to kicad version 6
    [Project_GP8B.kicad_pcb, Project_GP8B.kicad_sch, Project_GP8B.sch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]
2022-07-08 Updating descriptions
    [Project_GP8B.kicad_pcb, Project_GP8B.kicad_sch, fileConnector.kicad_sch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]
2022-09-20 convert custom lib to new kicad format
2022-09-20 Renaming COUNTER to SEQUENCE and others to make it clear
    [Project_GP8B.kicad_sch, fileConnector.kicad_sch, fileInstruction.kicad_sch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]
2022-09-21 Add more sequences to prepare 50MHz compatibility (removing clock sync)
    [Project_GP8B.kicad_sch, fileConnector.kicad_sch, fileInstruction.kicad_sch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]
2022-09-21 Finally remove clock sync, big improvement for the "if" instruction check (faster tps, less gates)
    [Project_GP8B.kicad_sch, fileConnector.kicad_sch, fileInstruction.kicad_sch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]
2022-09-21 bit of cleaning after last commit
    [Project_GP8B.kicad_sch, fileInstruction.kicad_sch, fileNumberSelect.kicad_sch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]
2023-03-18 updating to kicad 7, fix 3d model of Eurocard_5536475-1
    [Project_GP8B.kicad_pcb, Project_GP8B.kicad_sch, fileConnector.kicad_sch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]
2023-03-18 updating symbols ref, renaming some pins (NEXT_AFTERSET -> REQ_NEXT_AFTERISET)
    [Project_GP8B.kicad_sch, fileConnector.kicad_sch, fileInstruction.kicad_sch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]
2023-03-18 replace 74LS163 to 74LVC163 in order to reduce Tpd, with this replacement, CD74AC238 must be change to CD74ACT238
    [Project_GP8B.kicad_sch, fileConnector.kicad_sch, fileInstruction.kicad_sch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]
2023-08-10 replacing 10k pull-ups resistors with 1k in order to limit the effect on rise up time
    [Project_GP8B.kicad_sch, fileInstruction.kicad_sch]
2023-08-10 add a simulation with circuit verse
2023-08-11 update copyright date, replacing LVC163 -> LV163.
    [Project_GP8B.kicad_sch, fileConnector.kicad_sch, fileInstruction.kicad_sch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]
2023-08-20 update BOM
    [fileOperation.kicad_sch, fileRAM.kicad_sch, fileRegister.kicad_sch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]
